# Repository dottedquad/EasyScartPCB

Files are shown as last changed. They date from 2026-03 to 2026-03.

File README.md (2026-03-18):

# EasyScartPCB
A simplified SCART cable PCB optimized for US modded TVs and hand soldering

### Summary
This is a fork of [screwbreaker/ScartPCB](https://github.com/screwbreaker/ScartPCB) designed for SCART modding on US-market TVs. Since these TVs don't use the +12V auto-switch or aspect ratio signal (SCART pin 8), this design removes the unnecessary boost converter and optimizes for easier hand assembly and part sourcing.

### Key Improvements
- **Hand-solder friendly**: All 0805 components (no tiny 0402 parts)
- **Better component sourcing**: Single package "B" tantalum 220µF/6.3V for decoupling instead of multiple MLCCs
- **Simplified buffer**: Single 74LVC1G17 instead of two transistors
- **Complete grounding**: All SCART ground signals properly connected
- **Removes unnecessary boost converter**: US TVs don't need the +12V signal

### How It Works
The PCB is modular – use 0Ω resistors as jumpers to enable/disable signals as needed:

**CSYNC Buffer**: The 74LVC1G17 buffer is specifically for Genesis/Mega Drive systems. Genesis outputs a TTL-level CSYNC that loses voltage when loaded by the 470Ω series resistor and 75Ω termination resistor. The buffer maintains +5V for proper sync detection. Close the NOBUF jumper to bypass if not needed.

**RGB Signals**: Use 0Ω resistors to pass through or add 75Ω termination resistors as needed.

**Jumpers**: NOBUF (bypass CSYNC buffer), MONO (mix left/right audio), RGB (enable blanking signal).

### PCB Details
4-layer board designed to fit inside standard SCART connectors. All components are 0805 or larger for easy hand soldering.

### 3D-Printed Cable Gland
SCART connector cable glands are notoriously brittle, so this project includes a 3D-printed replacement that's more durable.

SCART_cable_gland

### License
The PCBs are under the CERN OHL license. This is an open project – improvements and contributions are welcome.

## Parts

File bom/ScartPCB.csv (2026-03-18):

Id | Designator | Footprint | Quantity | Designation | Supplier and ref
1 | RR1,RB1,RG1 | R_0805_2012Metric_Pad1.20x1.40mm_HandSolder | 3 | 75
2 | RG2,RB2,R8,RR2,RC2 | R_0805_2012Metric_Pad1.20x1.40mm_HandSolder | 5 | DNC
3 | CR1,CB1,CC1,CG1 | CP_EIA-3528-21_Kemet-B_HandSolder | 4 | 220uF
4 | C0 | C_0805_2012Metric_Pad1.18x1.45mm_HandSolder | 1 | 100nF
5 | R9 | R_0805_2012Metric_Pad1.20x1.40mm_HandSolder | 1 | 180
6 | U1 | SC-74A-5_1.55x2.9mm_P0.95mm | 1 | 74LVC1G17
7 | R7 | R_0805_2012Metric_Pad1.20x1.40mm_HandSolder | 1 | 0
8 | RC1 | R_0805_2012Metric_Pad1.20x1.40mm_HandSolder | 1 | 470

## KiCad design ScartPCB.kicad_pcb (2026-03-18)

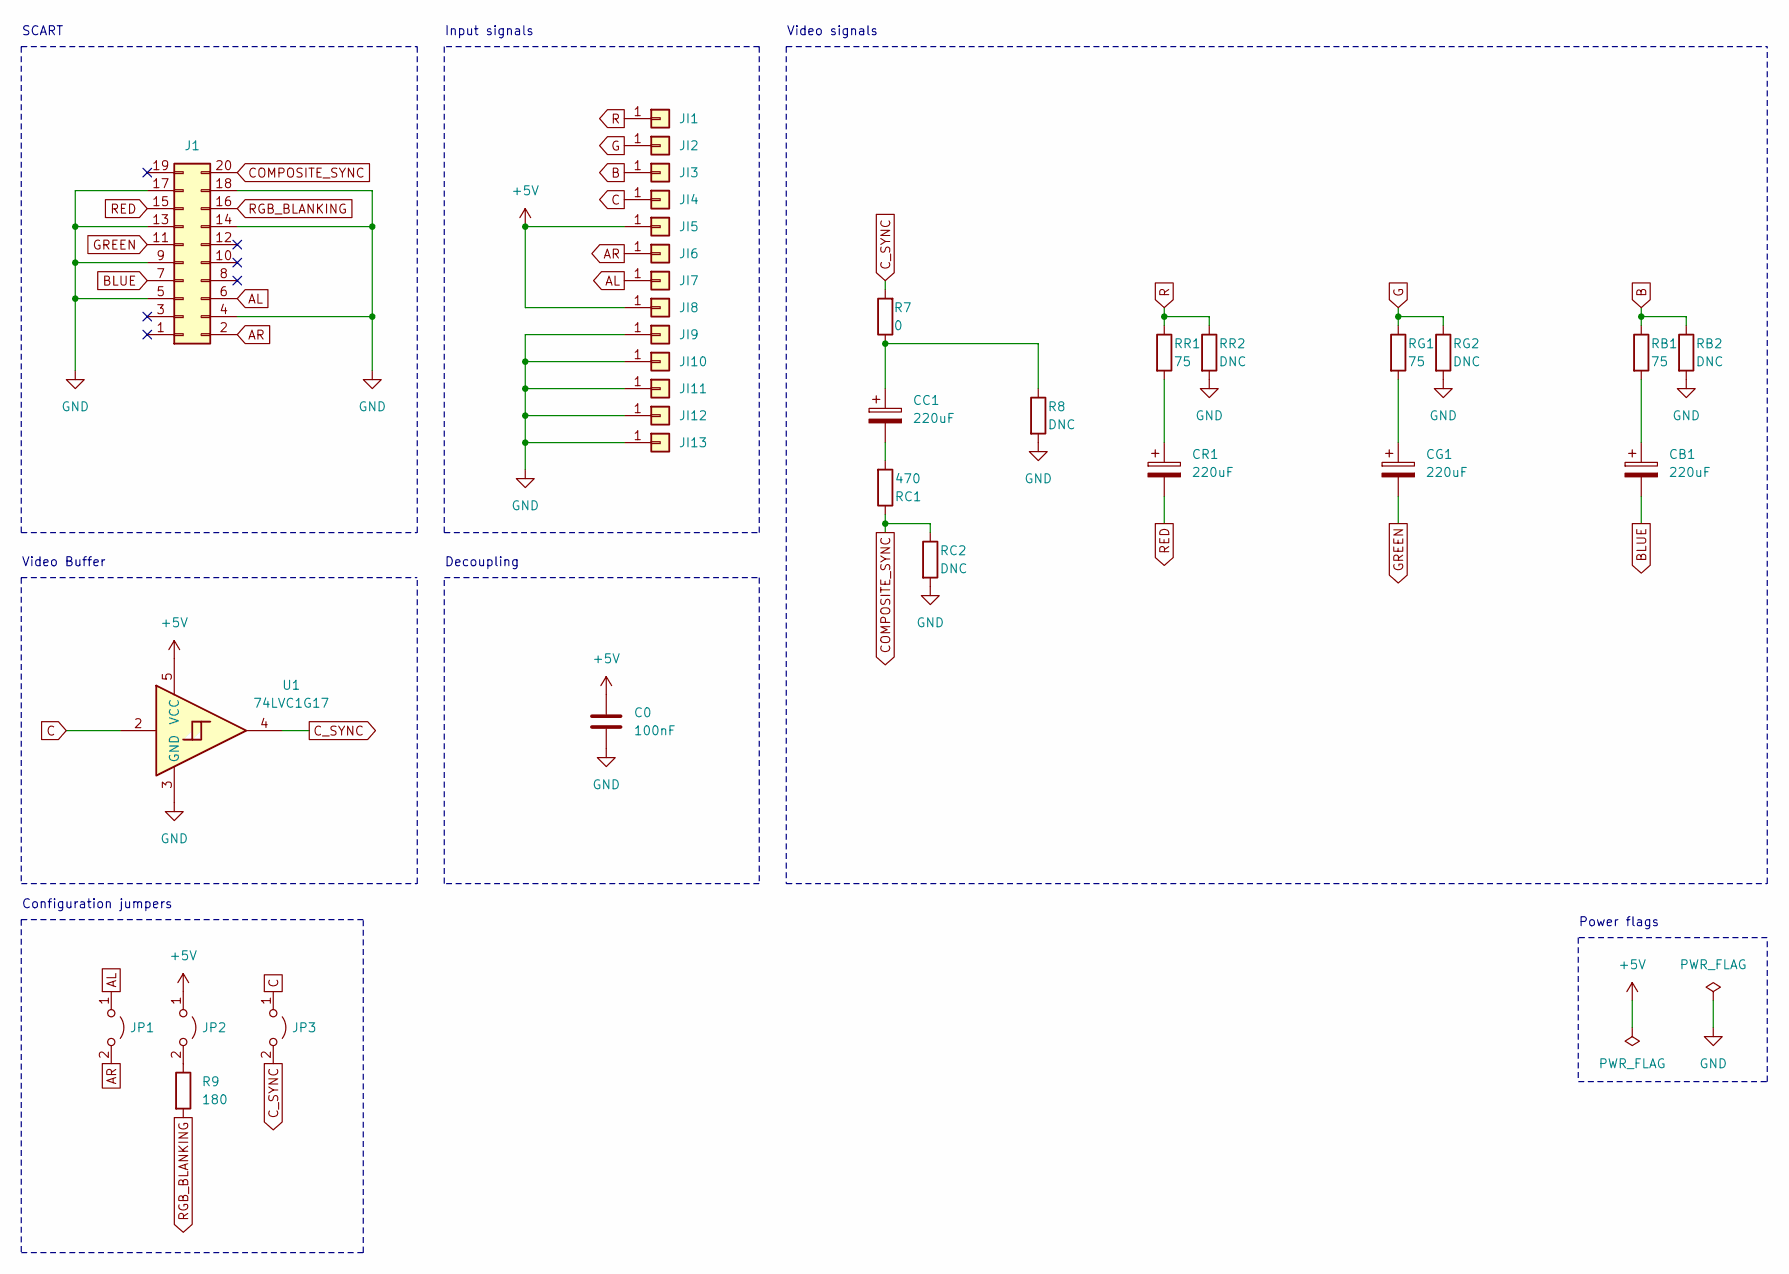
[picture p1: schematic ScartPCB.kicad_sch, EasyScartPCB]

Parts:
C0: 100nF; C_0805_2012Metric_Pad1.18x1.45mm_HandSolder
CB1: 220uF; CP_EIA-3528-21_Kemet-B_HandSolder
CC1: 220uF; CP_EIA-3528-21_Kemet-B_HandSolder
CG1: 220uF; CP_EIA-3528-21_Kemet-B_HandSolder
CR1: 220uF; CP_EIA-3528-21_Kemet-B_HandSolder
J1: Conn_02x10_Odd_Even; SCART
JI1, JI2, JI3, JI4, JI5, JI6, JI7, JI8, JI9, JI10, JI11, JI12: Conn_01x01; PAD2x2
JI13: Conn_01x01; PAD1.5x1.5
JP1, JP2, JP3: Jumper_2_Open; SolderJumper-2_P1.3mm_Open_TrianglePad1.0x1.5mm
R7: 0; R_0805_2012Metric_Pad1.20x1.40mm_HandSolder
R8: DNC; R_0805_2012Metric_Pad1.20x1.40mm_HandSolder
R9: 180; R_0805_2012Metric_Pad1.20x1.40mm_HandSolder
RB1: 75; R_0805_2012Metric_Pad1.20x1.40mm_HandSolder
RB2: DNC; R_0805_2012Metric_Pad1.20x1.40mm_HandSolder
RC1: 470; R_0805_2012Metric_Pad1.20x1.40mm_HandSolder; Manufacturer_Part_Number RC0402JR-07300RL
RC2: DNC; R_0805_2012Metric_Pad1.20x1.40mm_HandSolder
RG1: 75; R_0805_2012Metric_Pad1.20x1.40mm_HandSolder
RG2: DNC; R_0805_2012Metric_Pad1.20x1.40mm_HandSolder
RR1: 75; R_0805_2012Metric_Pad1.20x1.40mm_HandSolder
RR2: DNC; R_0805_2012Metric_Pad1.20x1.40mm_HandSolder
U1: 74LVC1G17; SC-74A-5_1.55x2.9mm_P0.95mm

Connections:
+5V: C0.1, JI5.1, JI8.1, JP2.1 (A), U1.5 (VCC)
AL: J1.6, JI7.1, JP1.1 (A)
AR: J1.2, JI6.1, JP1.2 (B)
B: JI3.1, RB1.1, RB2.1
BLUE: CB1.2, J1.7
C: JI4.1, JP3.1 (A), U1.2
COMPOSITE_SYNC: J1.20, RC1.1, RC2.1
C_SYNC: JP3.2 (B), R7.2, U1.4
G: JI2.1, RG1.1, RG2.1
GND: C0.2, J1.4, J1.5, J1.9, J1.13, J1.14, J1.17, J1.18, JI9.1, JI10.1, JI11.1, JI12.1, JI13.1, R8.2, RB2.2, RC2.2, RG2.2, RR2.2, U1.3 (GND)
GREEN: CG1.2, J1.11
unnamed: CB1.1, RB1.2
unnamed: CC1.1, R7.1, R8.1
unnamed: CC1.2, RC1.2
unnamed: CG1.1, RG1.2
unnamed: CR1.1, RR1.2
unnamed: JP2.2 (B), R9.1
R: JI1.1, RR1.1, RR2.1
RED: CR1.2, J1.15
RGB_BLANKING: J1.16, R9.2

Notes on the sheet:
Configuration jumpers
Power flags
Decoupling
Video Buffer
SCART
Input signals
Video signals

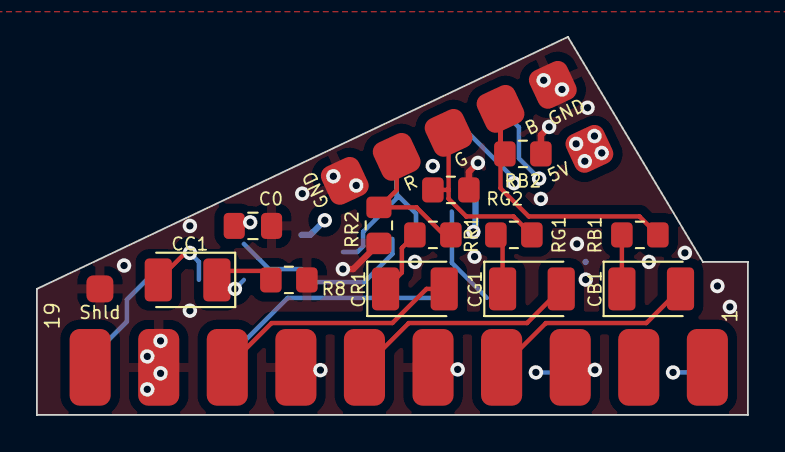
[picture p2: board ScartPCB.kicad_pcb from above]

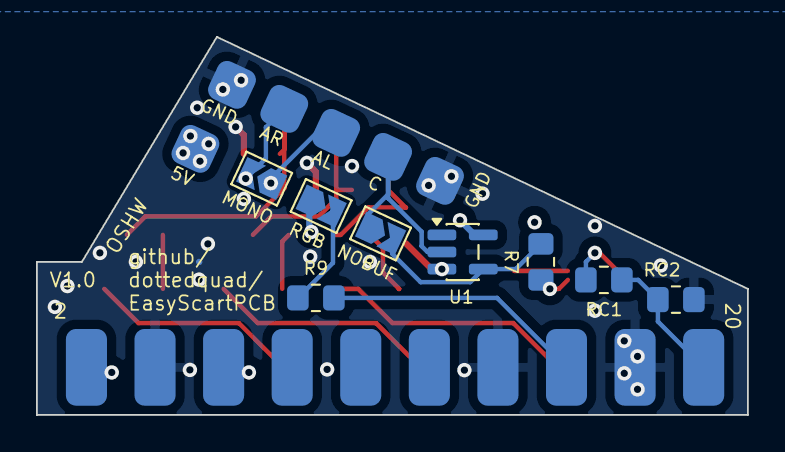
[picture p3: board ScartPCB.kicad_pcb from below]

Board: 4 copper layers, 39.5 x 21.0 mm, 34 parts (14 on the bottom side), 20 nets.

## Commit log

2026-03-17 Change it to work more like I want it to
    [ScartPCB.kicad_pcb, ScartPCB.kicad_sch]
2026-03-18 tweak position of csync cap
    [ScartPCB.kicad_pcb]
2026-03-18 Get ready for first run
    [ScartPCB-B_Cu.gbr, ScartPCB-B_Mask.gbr, ScartPCB-B_Paste.gbr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]
